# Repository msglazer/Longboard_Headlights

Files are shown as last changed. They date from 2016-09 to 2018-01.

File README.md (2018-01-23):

# Longboard_Headlights
Headlights and Taillights for Longboard project

### Wired Headlight/Tail-light Module:

2X White/Red 1W LED's powered by E-board battery pack
12S(50.4V) Tolerant

### Battery Headlight/Tail-light Module:

2X White/Red 1W LED's powered by an 18650
3+ Hour battery life

#### Common features and Other Info:
Wired version is capable of dimming control through microcontroller, should also be able to make it flash this way as well
Both designs will be mounted through a truck riser. Wired version uses a 1/2" riser.

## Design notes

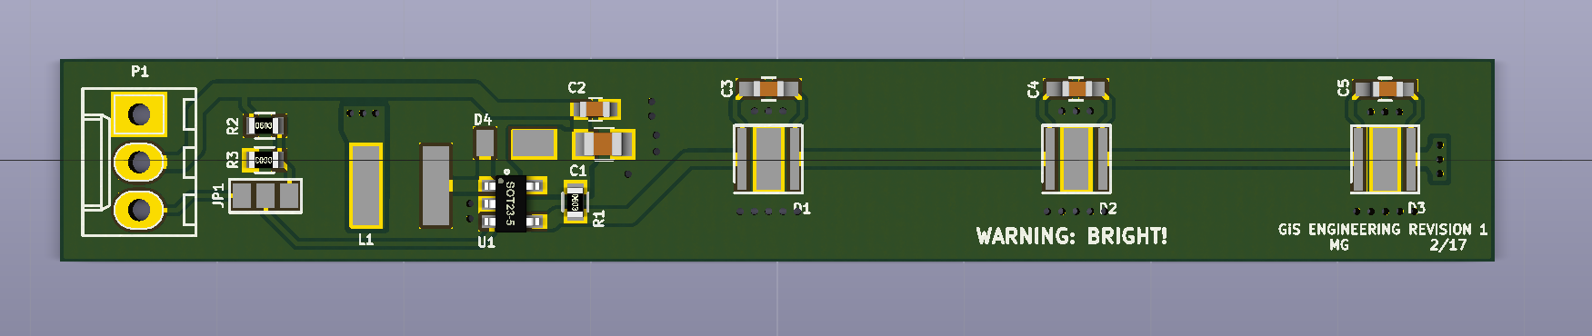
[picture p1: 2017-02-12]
images/PCB_Front.PNG

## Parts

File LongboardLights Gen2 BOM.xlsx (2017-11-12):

Bill of Materials (BOM) - LongboardLights
 |  |  | Green - Forward Lighting, Blue - Rear Lighting, Orange - PCB
Item # | Board Qty | Prod. Qty | Ref Des | Manufacturer | Mfg Part # | Dist. Part # | Price Per Unit | Total Price | Description | Package | Type | Datasheet
1 | 1 | 1 | U1 | Texas Instruments | BQ29700DSER | 296-43985-1-ND | $0.69 | $0.69 | Battery Protection IC | 6-WFDFN | SMD | http://www.ti.com/lit/ds/symlink/bq2971.pdf
3 | 1 | 1 | U2 | Microchip Technology | MCP73833T-FCI/MF | MCP73833T-FCI/MFCT-ND | $0.89 | $0.89 | Battery Charger IC | 10-DFN | SMD | http://www.microchip.com/mymicrochip/filehandler.aspx?ddocname=en027983
4 | 1 | 1 | U3 | Diodes Inc | AP5724FDCG-7 | AP5724FDCGDICT-ND | $0.45 | $0.45 | LED Driver IC | 16-WFQFN | SMD | http://www.ti.com/lit/ds/symlink/tps55330.pdf
5 | 1 | 1 | Q1 | Diodes Inc | DMN2040LTS-13 | DMN2040LTS-13DICT-ND | $0.46 | $0.46 | Dual NMOS common drain | 8-TSSOP | SMD | https://www.diodes.com/assets/Datasheets/ds31941.pdf
6 | 2 | 2 | D2,D3 | Cree Inc | XPGDWT-B1-0000-00LE1 | XPGDWT-B1-0000-00LE1CT-ND | $1.14 | $2.28 | 6500K White LED | 1414 | SMD | http://www.cree.com/led-components/media/documents/dsXPG3.pdf
6 | 2 | 2 | D2,D3 | Cree Inc | XPCRED-L1-R250-00201CT-ND | 941-XPCREDL1R250201 | $1.22 | $2.44 | Red LED | SMD-2 | SMD
7 | 1 | 1 | D1 | Diodes Inc | SS24FL | SS24FLCT-ND | $0.39 | $0.39 | Schottky Diode | SOD-123F | SMD | https://www.fairchildsemi.com/datasheets/SS/SS24FL.pdf
8 | 1 | 1 | C1 | Samsung | CL10B104KO8NNNC | 1276-1005-1-ND | $0.10 | $0.10 | 0.1uF Capacitor | 0603 | SMD
9 | 2 | 2 | C2,C3 | Samsung | CL10A475KO8NNNC | 1276-1784-1-ND | $0.26 | $0.52 | 4.7uF Capacitor | 0603 | SMD
11 | 1 | 1 | C4 | Samsung | CL21A106KOQNNNG | 1276-6455-1-ND | $0.13 | $0.13 | 10uF Capacitor | 0805 | SMD
15 | 1 | 1 | R6 | Samsung | RUT1608FR300CS | 1276-6168-1-ND | $0.17 | $0.17 | 0.3 ohm Resistor | 0603 | SMD
17 | 3 | 1 | R3 | Yageo | RC0603FR-0710KL | 311-10.0KHRCT-ND | $0.10 | $0.10 | 10k ohm resistor | 0603 | SMD
18 | 1 | 1 | R1 | Yageo | RC0603JR-072K2L | 311-2.2KGRCT-ND | $0.10 | $0.10 | 2.2K Ohm Resistor | 0603 | SMD
19 | 1 | 1 | R2 | Yageo | RC0603JR-07330RL | 311-330GRCT-ND | $0.10 | $0.10 | 330 Ohm Resistor | 0603 | SMD
22 | 1 | 1 | R4 | Yageo | RC0603JR-0720KL | 311-20KGRCT-ND | $0.10 | $0.10 | 20K Ohm Resistor | 0603 | SMD
23 | 1 | 1 | R5 | Yageo | RC0603FR-071KL | 311-1.00KHRCT-ND | $0.10 | $0.10 | 1K Ohm Resistor | 0603 | SMD
25 | 1 | 1 | L1 | Taiyo Yuden | NRS4018T220MDGJ | 587-2889-1-ND | $0.29 | $0.29 | 22uH Inductor | 6mm x 6mm | SMD
27 | 1 | 1 | B1 | Keystone Electronics | 1043 | 36-1043-ND | $2.31 | $2.31 | Battery Holder |  | ThruHole
28 | 1 | 1 | SW1 | CW Industries | GPTS203212B | CW182-ND | $0.74 | $0.74 | Power Button |  | ThruHole
29 | 1 | 1 | J1 | Amphenol | 10118194-0001LF | 609-4618-1-ND | $0.46 | $0.46 | Micro USB Port
30 | 1 | 1 | PCB | Oshpark | LR8zDDeL |  | $5.00 | $5.00 | PCB
 |  |  |  |  |  | Board Multiplier: | 1 | Headlight Total:
 |  |  |  |  |  |  |  | $10.38
 |  |  |  |  |  |  |  | Taillight Total:
 |  |  |  |  |  |  |  | $10.54
 |  |  |  |  |  |  |  | PCB Total:
 |  |  |  |  |  |  |  | $5.00
 |  |  |  |  |  |  |  | Grand Total:
 |  |  |  |  |  |  |  | $30.92

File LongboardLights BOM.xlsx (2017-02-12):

Bill of Materials (BOM) - LongboardLights
 |  | Green - Forward Lighting, Blue - Rear Lighting, Orange - PCB
Item # | Qty | Ref Des | Manufacturer | Mfg Part # | Dist. Part # | Price Per Unit | Total Price | Description | Package | Type | Datasheet | Notes
1 | 2 | Q1 | Diodes Inc | AL8805W5-7 | 621-AL8805W5-7 | $0.87 | $1.74 | LED Driver | SOT-25 | SMD | http://www.mouser.com/ds/2/115/AL8805-59388.pdf
2 | 6 | D1,D2,D3 | Cree Inc | XPGDWT-B1-0000-00LE3 | 941-XPGDWTB100LE3 | $1.79 | $10.74 | White LED | SMD-2 | SMD | http://www.mouser.com/ds/2/90/dsXPG3-931454.pdf
3 | 2 | C1 | Murata Electronics | GRM21BR61E475KA12L | 81-GRM21BR61E475KA12 | $0.15 | $0.30 | 4.7uF Capacitor | 0805 | SMD
4 | 2 | C2 | Murata Electronics | GRM188R61E225MA12D | 81-GRM188R61E225MA2D | $0.12 | $0.24 | 2.2uF Capacitor | 0603 | SMD
5 | 6 | C3,C4,C5 |  | GRM188R61E105KA12D | 81-GRM188R61E105KA12 | $0.10 | $0.60 | 1uF Capacitor | 0603 | SMD
6 | 2 | R1 | TE Connectivity | RLP73N2AR30JTD | 279-RLP73N2AR30JTD | $0.10 | $0.20 | 0.3 ohm resistor | 0603 | SMD
7 | 2 | R2 | Yageo | RC0603FR-0738K3L | 603-RC0603FR-0738K3L | $0.09 | $0.18 | 38k ohm resistor | 0603 | SMD |  | order 10
8 | 2 | R3 | Panasonic | ERJ-3GEYJ103V | 667-ERJ-3GEYJ103V | $0.08 | $0.16 | 10k ohm resistor | 0603 | SMD
9 | 2 | L1 | Laird Technologies | TYS5040101M-10 | 875-TYS5040101M-10 | $0.51 | $1.02 | 100uH Inductor | 5mm x 5mm | SMD | http://www.mouser.com/ds/2/223/SIP-DS-TYS%205040%200413-537395.pdf
10 | 2 | D4 | Diodes Inc | DFLS1200-7 | 621-DFLS1200-F | $0.58 | $1.16 | Schottky Diode | PowerDI-123 | SMD
12 | 6 | D1,D2 | Cree Inc | XPCRED-L1-R250-00201 | 941-XPCREDL1R250201 | $1.58 | $9.48 | Red LED | SMD-2 | SMD
23 | 1 | PCB | Oshpark | LR8zDDeL |  | $2.15 | $2.15
 |  |  |  |  | Board Multiplier: | 2 | Headlight Total:
 |  |  |  |  |  |  | $16.34
 |  |  |  |  |  |  | Taillight Total:
 |  |  |  |  |  |  | $15.08
 |  |  |  |  |  |  | PCB Total:
 |  |  |  |  |  |  | $2.15
 |  |  |  |  |  |  | Grand Total:
 |  |  |  |  |  |  | $35.72

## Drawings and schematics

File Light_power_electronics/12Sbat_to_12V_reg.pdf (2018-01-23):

## WEBENCH ® Design Report

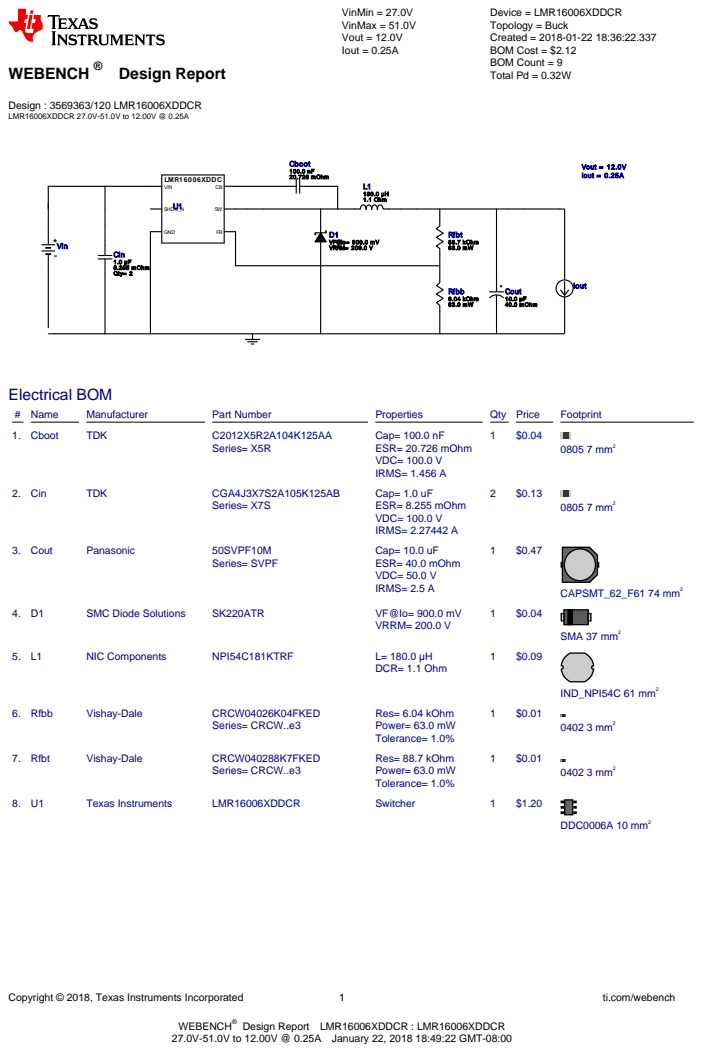
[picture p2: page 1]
Copyright © 2018, Texas Instruments Incorporated; ti.com/webench; Design Report LMR16006XDDCR : LMR16006XDDCR; Design : 3569363/120 LMR16006XDDCR LMR16006XDDCR 27.0V-51.0V to 12.00V @ 0.25A; VinMin = 27.0V VinMax = 51.0V Vout = 12.0V Iout = 0.25A; Device = LMR16006XDDCR Topology = Buck Created = 2018-01-22 18:36:22.337 BOM Cost = $2.12 BOM Count = 9 Total Pd = 0.32W; Cboot 100.0 nF 20.726 mOhm; Cin 1.0 µF 8.255 mOhm Qty= 2; Cout 10.0 µF 40.0 mOhm; D1 VF@Io= 900.0 mV VRRM= 200.0 V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

WEBENCH®
27.0V-51.0V to 12.00V @ 0.25A January 22, 2018 18:49:22 GMT-08:00

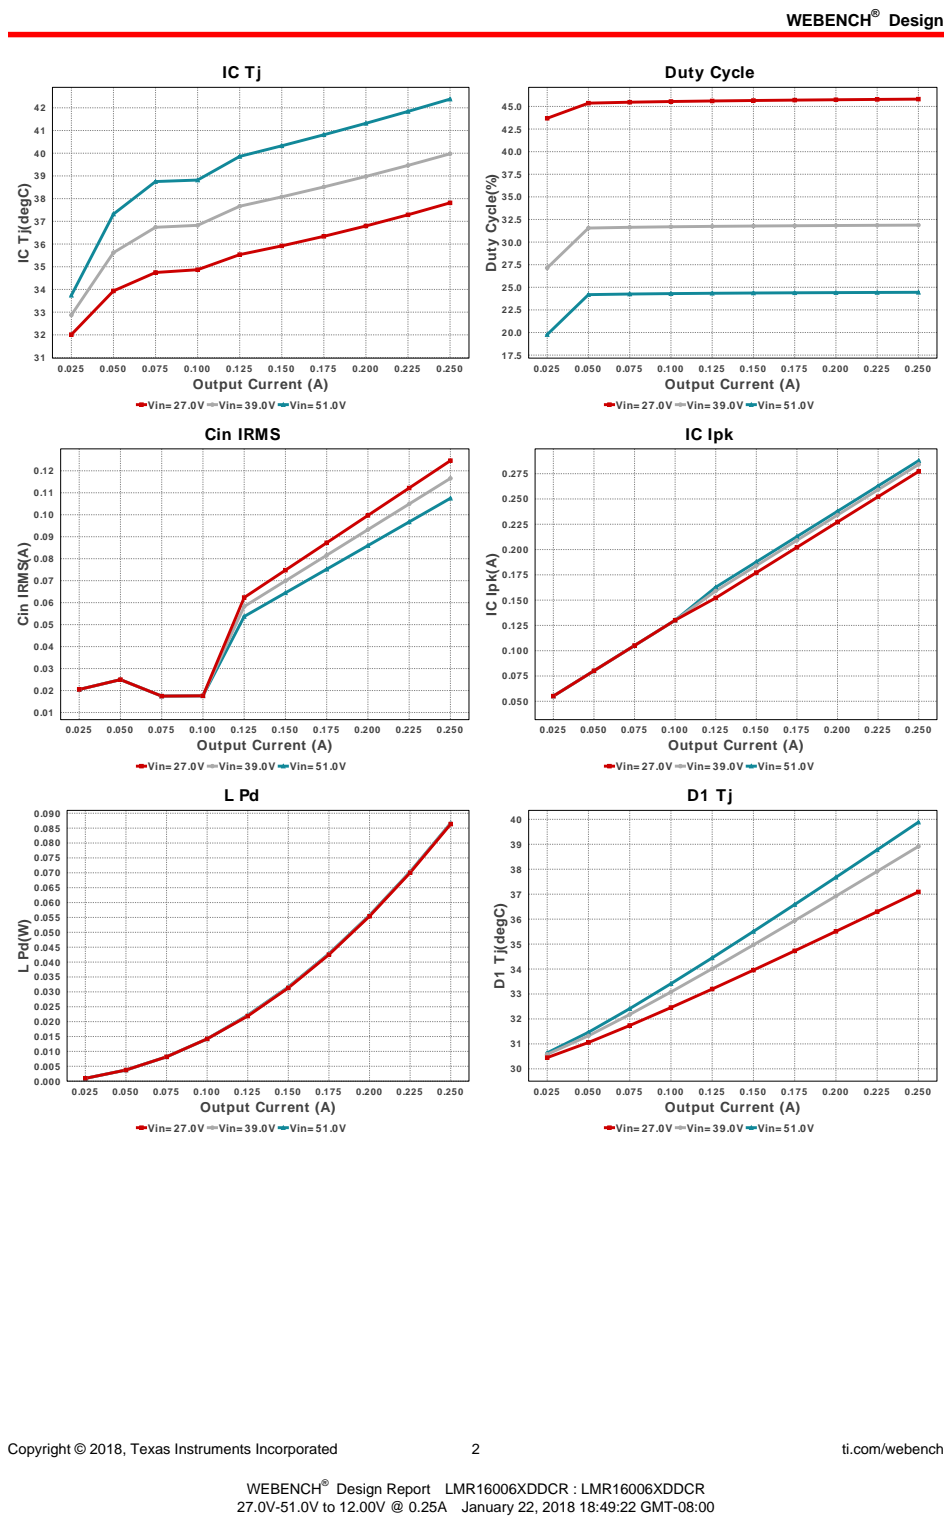
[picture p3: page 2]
Design; Copyright © 2018, Texas Instruments Incorporated; ti.com/webench; 0.250 Output Current (A); Duty Cycle; Duty Cycle(%); Cin IRMS(A); IC Ipk; IC Ipk(A); D1 Tj(degC)

IC Tj(degC)

Vin= 27.0V Vin= 39.0V Vin= 51.0V
Cin IRMS

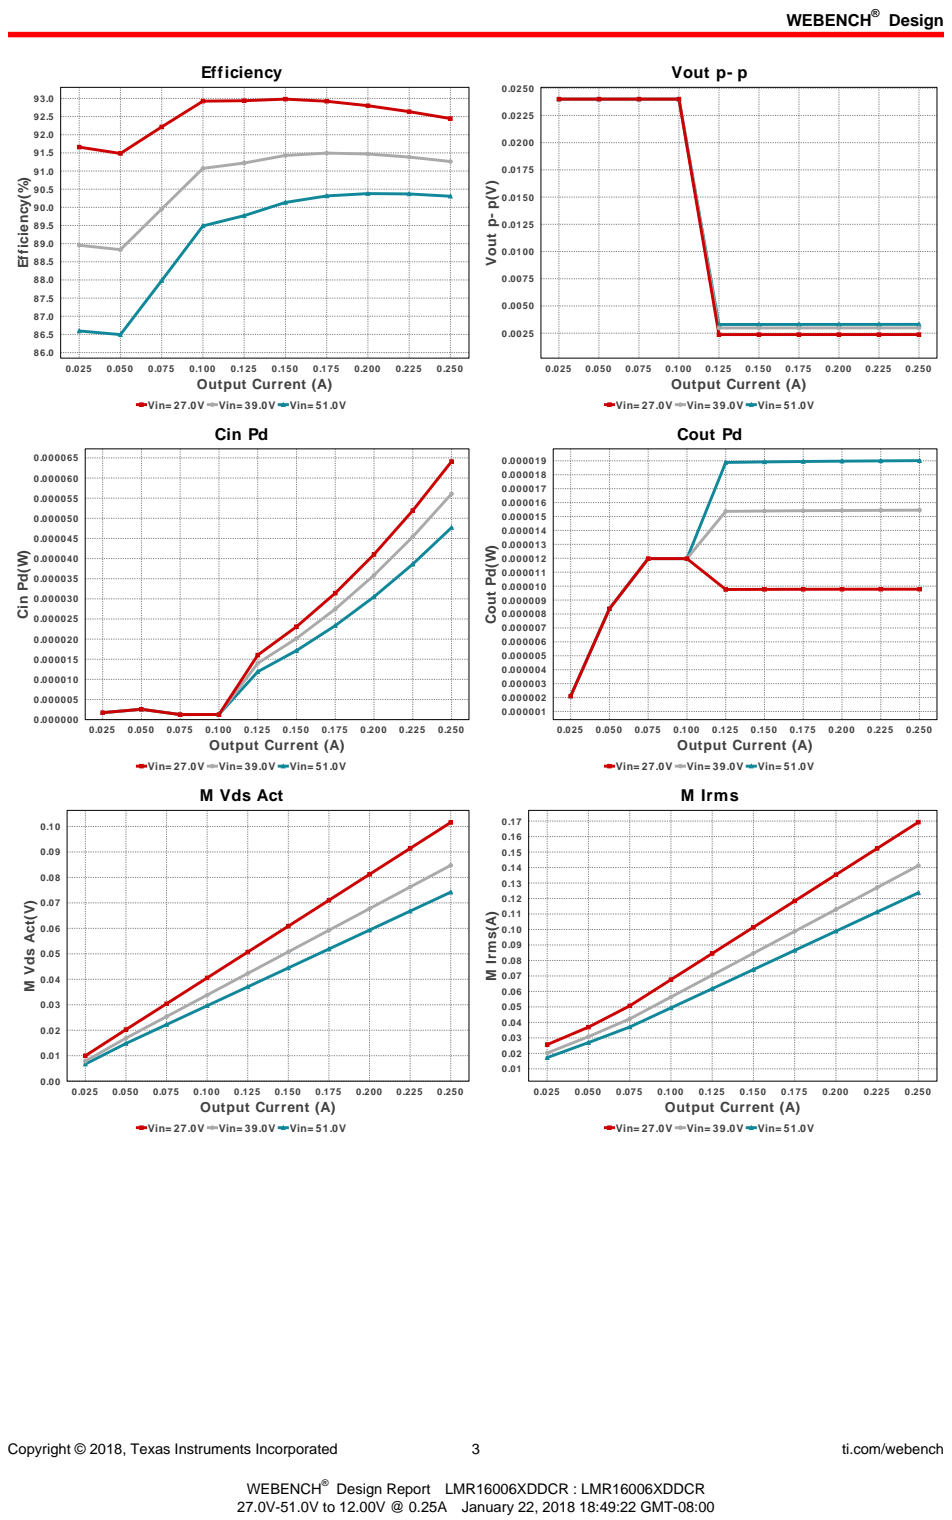
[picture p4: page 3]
Copyright © 2018, Texas Instruments Incorporated; ti.com/webench; Efficiency; 0.250 Output Current (A); Efficiency(%); Vout p- p; Vout p- p(V); Cin Pd; 0.025 0.050 0.075 0.100 0.125 0.150 0.175 0.200 0.225 0.250 Output Current (A); Cin Pd(W); Cout Pd; Cout Pd(W); M Vds Act(V); M Irms; M Irms(A)

Vin= 27.0V Vin= 39.0V Vin= 51.0V

M Vds Act

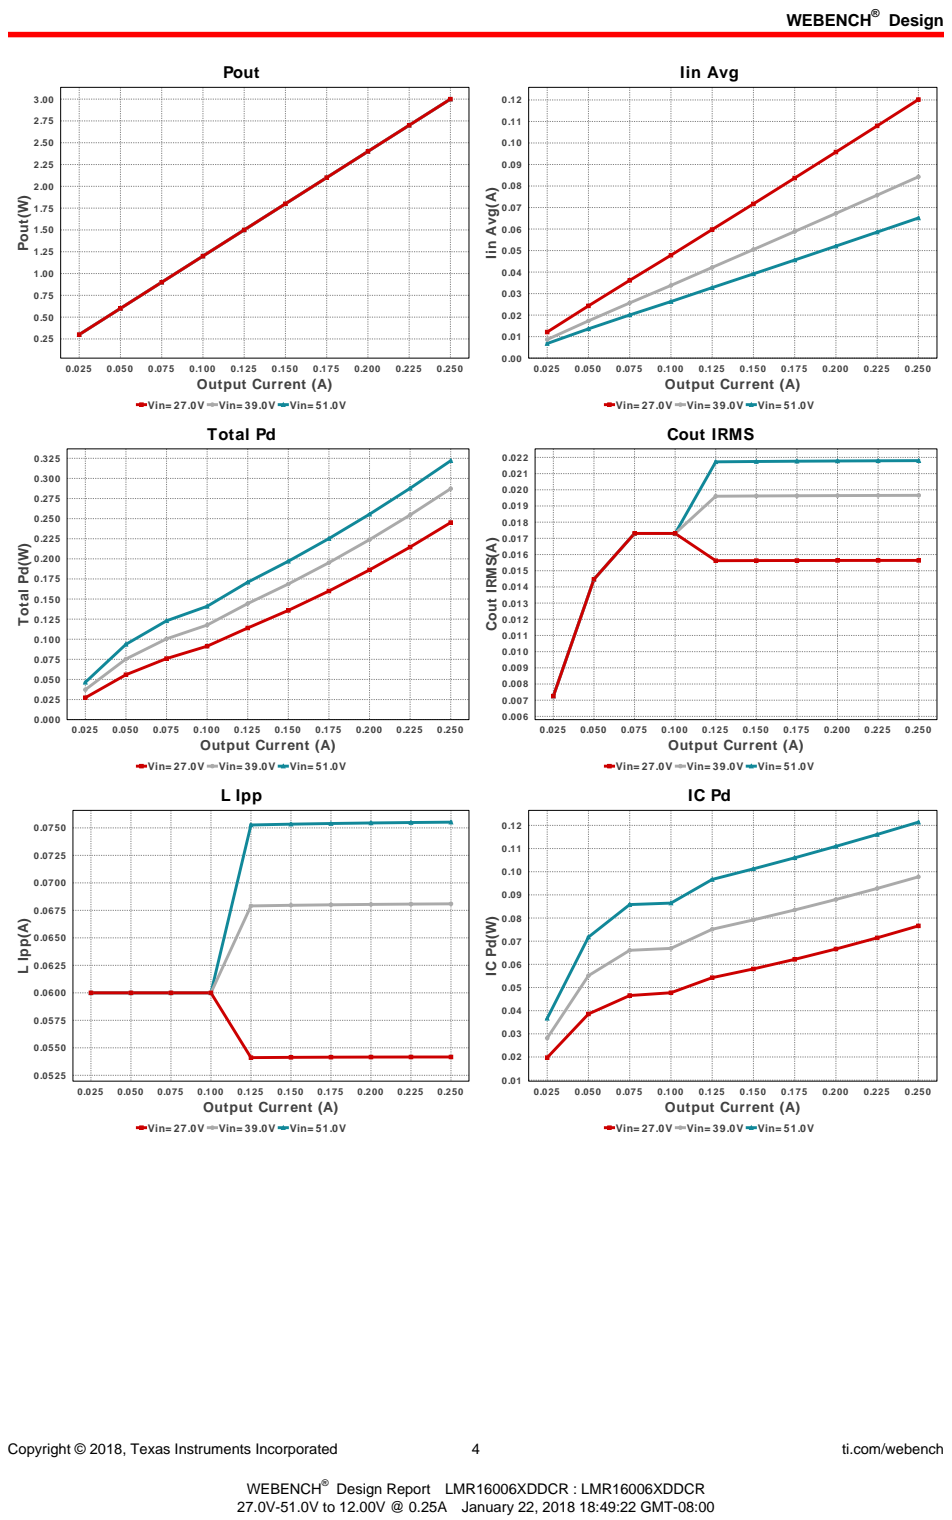
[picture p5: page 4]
Copyright © 2018, Texas Instruments Incorporated; ti.com/webench; Pout; 0.250 Output Current (A); Pout(W); Iin Avg; Iin Avg(A); Total Pd; Total Pd(W); Cout IRMS(A); L Ipp; L Ipp(A)

Vin= 27.0V Vin= 39.0V Vin= 51.0V

Cout IRMS

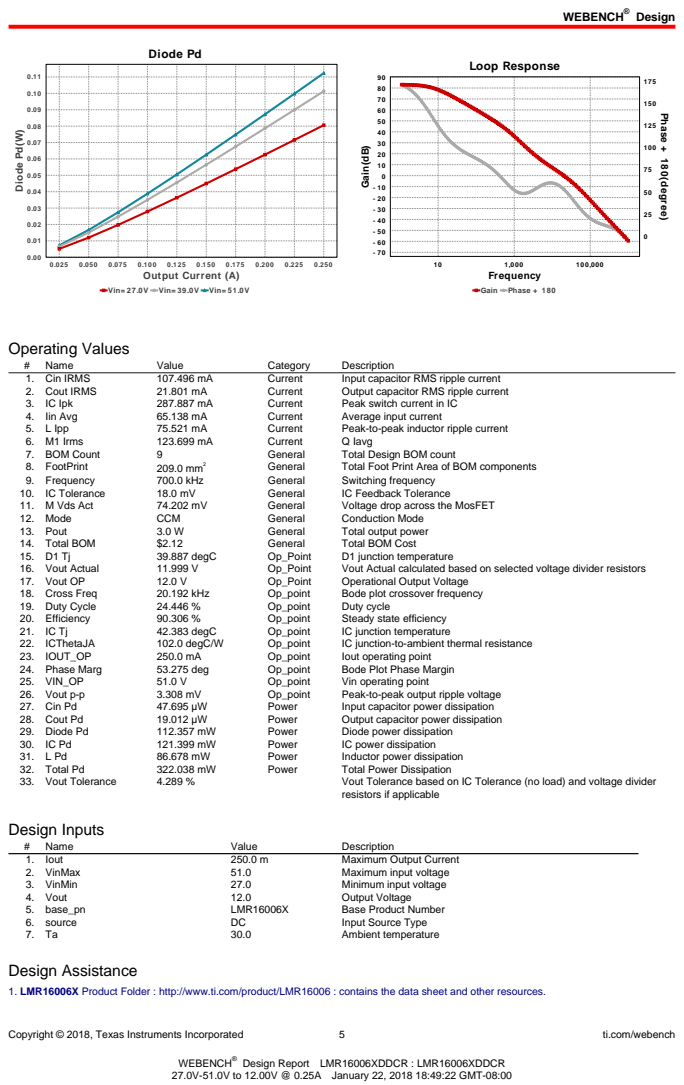
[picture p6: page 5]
Copyright © 2018, Texas Instruments Incorporated; ti.com/webench; Diode Pd; 0.250 Output Current (A); Diode Pd(W); Loop Response; Gain Phase + 180; 100,000 Frequency; Gain(dB); Phase + 180(degree); Operating Values; Name; Value; Category; Description; 1. Cin IRMS; Current; Input capacitor RMS ripple current; 2. Cout IRMS; Output capacitor RMS ripple current; 3. IC Ipk; Peak switch current in IC; 4. Iin Avg; Average input current; 5. L Ipp; Peak-to-peak inductor ripple current; 6. M1 Irms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

Vin= 27.0V Vin= 39.0V Vin= 51.0V

resistors if applicable

1. LMR16006X Product Folder : http://www.ti.com/product/LMR16006 : contains the data sheet and other resources.

Copyright © 2018, Texas Instruments Incorporated | 6 | ti.com/webench

Texas Instruments' WEBENCH simulation tools attempt to recreate the performance of a substantially equivalent physical implementation
of the design. Simulations are created using Texas Instruments' published specifications as well as the published specifications of other device manufacturers. While Texas Instruments does update this information periodically, this information may not be current at the time the simulation is built. Texas Instruments does not warrant the accuracy or completeness of the specifications or any information contained therein. Texas Instruments does not warrant that any designs or recommended parts will meet the specifications you entered, will be suitable for your application or fit for any particular purpose, or will operate as shown in the simulation in a physical implementation. Texas Instruments does not warrant that the designs are production worthy.
You should completely validate and test your design implementation to confirm the system functionality for your application prior to production.
Use of Texas Instruments' WEBENCH simulation tools is subject to Texas Instruments' Site Terms and Conditions of Use. (http://www.ti.com/corp/docs/legal/termsofuse.shtml) Prototype boards based on WEBENCH created designs are provided AS IS without warranty of any kind for evaluation and testing purposes and are subject to the terms of the Evaluation License Agreement. (http://www.ti.com/corp/docs/legal/termsofuse_estore.shtml)

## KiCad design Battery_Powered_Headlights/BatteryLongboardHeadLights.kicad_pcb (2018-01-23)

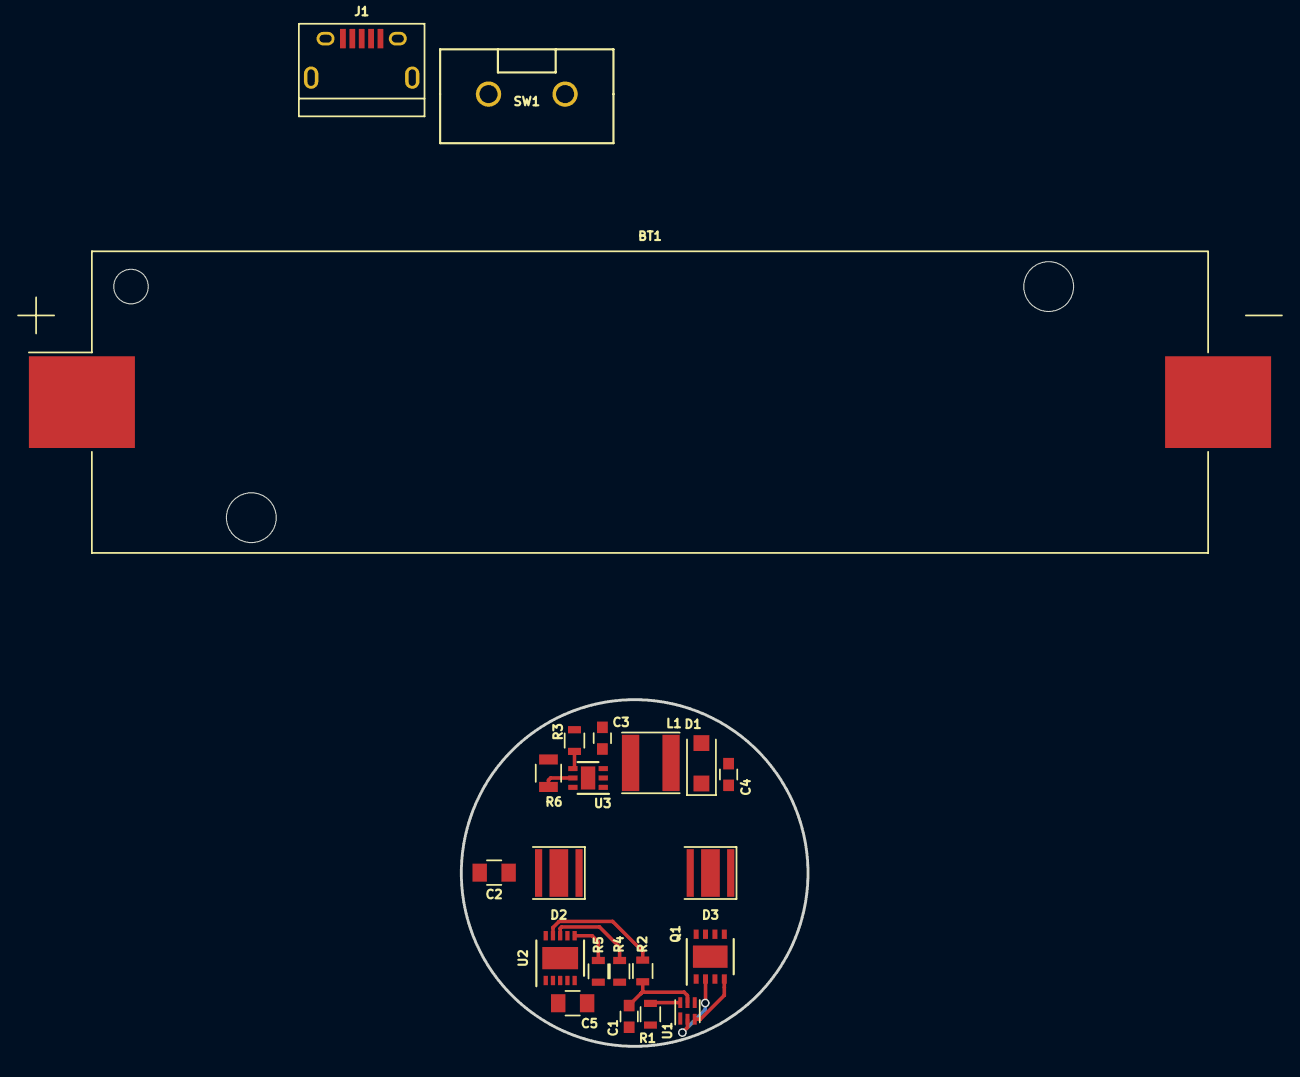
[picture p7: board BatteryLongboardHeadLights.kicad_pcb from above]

Board: 2 copper layers, 24.0 x 24.0 mm, 22 parts (0 on the bottom side), 15 nets.

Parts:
BT1: Battery_Cell; Keystone_1042_1x18650
C1: 0.1uF; C_0603
C2, C5: 4.7uF; C_0805
C3: 4.7uF; C_0603
C4: 10uF; C_0603
D1: D_Schottky; D_SOD-123F
D2, D3: LED; LED_Cree-XP-G
J1: USB_OTG; USB_Micro-B
L1: 22uH; L_Taiyo-Yuden_NR-40xx
Q1: DMN2028UFDH-7; DFN-8-1EP_3x3mm_Pitch0.65mm
R1: 2.2K; R_0603
R2: 330; R_0603
R3: 10K; R_0603
R4: 20K; R_0603
R5: 1K; R_0603
R6: 0.3; R_0805
SW1: SW_Push; GPTS203212B
U1: bq29700; WSON6_1.5x1.5mm_Pitch0.5mm
U2: MCP73833T; DFN-10-1EP_3x3mm_Pitch0.5mm
U3: AP5724; DFN-6-1EP_2x2mm_Pitch0.65mm

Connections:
+BATT: BT1.1, C2.1, C3.1, L1.1, R2.1, SW1.1, U2.9, U2.10, U3.2
/SWITCH: R3.1, SW1.2, U3.4
/USB_IN: C5.1, J1.1, U2.1, U2.2
/VBAT_NEG: BT1.2, C1.2, Q1.3, R1.2, U1.4
GND: C2.2, C3.2, C4.2, C5.2, J1.5, J1.6, Q1.1, R3.2, R4.2, R5.2, R6.2, U2.5, U3.6
unnamed: C1.1, R2.2, U1.5
unnamed: C4.1, D1.1, D2.2, U3.3
unnamed: D1.2, L1.2, U3.1
unnamed: D2.1, D3.2
unnamed: D3.1, R6.1, U3.5
unnamed: Q1.2, U1.2
unnamed: Q1.4, U1.3
unnamed: R1.1, U1.6
unnamed: R4.1, U2.8
unnamed: R5.1, U2.6

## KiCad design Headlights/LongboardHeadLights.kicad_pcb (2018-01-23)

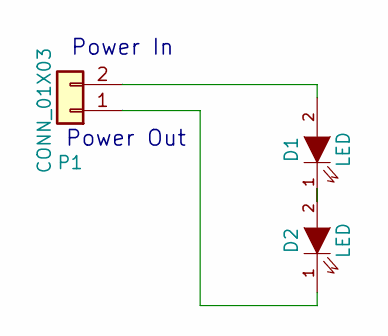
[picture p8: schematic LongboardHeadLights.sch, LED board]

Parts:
D1, D2: LED; LED-XP-G_CREE
P1: CONN_01X03; JST_EH_B02B-EH-A_02x2.50mm_Straight

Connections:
GND: D1.3, D2.3
unnamed: D1.1 (K), D2.2 (A)
unnamed: D1.2 (A), P1.2
unnamed: D2.1 (K), P1.1

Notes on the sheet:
Power In
Power Out

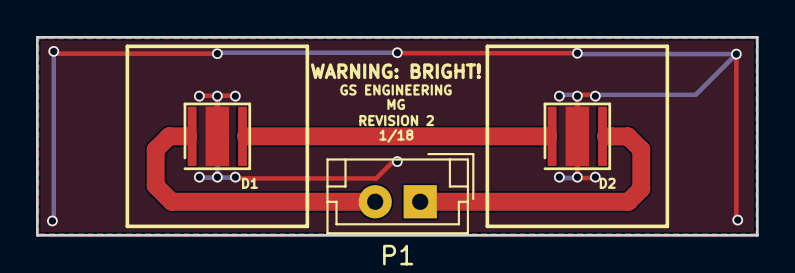
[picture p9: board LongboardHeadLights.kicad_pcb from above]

Board: 2 copper layers, 40.0 x 11.0 mm, 3 parts (0 on the bottom side), 4 nets.

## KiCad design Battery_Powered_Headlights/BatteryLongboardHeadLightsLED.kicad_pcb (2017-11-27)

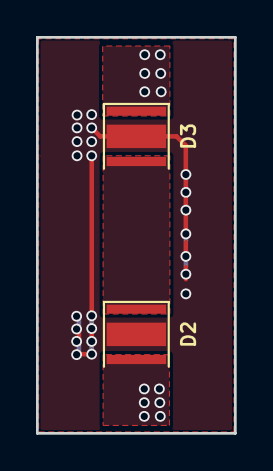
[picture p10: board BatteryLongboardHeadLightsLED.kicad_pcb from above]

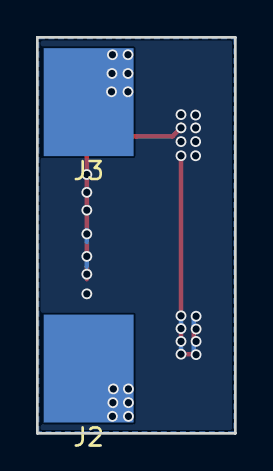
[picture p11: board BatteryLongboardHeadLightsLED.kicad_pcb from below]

Board: 2 copper layers, 11.0 x 22.0 mm, 4 parts (2 on the bottom side), 4 nets.

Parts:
D2, D3: LED; LED_Cree-XP-G
J2, J3: Conn_01x01; SolderWirePad_single_SMD_5x6mm

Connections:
GND: D2.3, D3.3
unnamed: D2.2, J2.1
unnamed: D2.1, D3.2
unnamed: D3.1, J3.1

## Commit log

2016-10-01 initial schematic build out
2016-10-14 PCB work
2016-10-14 small schematic changes
    [LongboardHeadLights.sch, LongboardTailLights.sch]
2016-10-14 updated BOM
    [LongboardLights BOM.xlsx]
2016-11-16 Generated Gerbers
    [LongboardHeadLights-B.Adhes.gbr, LongboardHeadLights-B.Cu.gbr, LongboardHeadLights-B.Mask.gbr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]
2016-11-16 updated project and completed rev 1 PCB
    [LongboardHeadLights.kicad_pcb]
2017-02-11 finished PCB, updating plan
    ditched tail light turn signal idea, now only need one PCB and just
    switch out LEDs
    [LongboardHeadLights.kicad_pcb, LongboardHeadLights.sch, LongboardLights BOM.xlsx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]
2017-02-11 couple quick changes
    [LongboardHeadLights.kicad_pcb, LongboardHeadLights.sch]
2017-02-11 fixed a bad trace
    [LongboardHeadLights.kicad_pcb]
2017-02-11 yet another fix
    [LongboardHeadLights.kicad_pcb]
2017-02-12 another small tweak
    [LongboardHeadLights.kicad_pcb]
2017-02-12 added a PCB image
2017-02-12 fixed BOM
    [LongboardLights BOM.xlsx]
2017-10-31 redesigning the headlights to be battery powered
    [BatteryLongboardHeadLights.kicad_pcb, BatteryLongboardHeadLights.sch, LongboardLights Gen2 BOM.xlsx]
2017-11-01 schematic changes nearly done
    [BatteryLongboardHeadLights.sch]
2017-11-01 updating BOM
    [LongboardLights Gen2 BOM.xlsx]
2017-11-02 Schematic done, values almost, layout next
    [BatteryLongboardHeadLights.sch]
2017-11-02 BOM update
    [LongboardLights Gen2 BOM.xlsx]
2017-11-06 schematic completed
    [BatteryLongboardHeadLights.sch]
2017-11-06 BOM completed
    [LongboardLights Gen2 BOM.xlsx]
2017-11-12 PCB work in progress
    [BatteryLongboardHeadLights.kicad_pcb]
2017-11-19 PCB layout for the Batteryboard/LEDcontroller done
    [BatteryLongboardHeadLights.kicad_pcb, BatteryLongboardHeadLightsLED.kicad_pcb, _saved_BatteryLongboardHeadLights.sch]
2017-11-27 PCB's should now be orderable
    [BatteryLongboardHeadLights.kicad_pcb, BatteryLongboardHeadLightsLED.kicad_pcb]
2018-01-23 updating designs for newest revision; removing unneeded files
    [BatteryLongboardHeadLights.kicad_pcb, BatteryLongboardHeadLights.sch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]
2018-01-23 bulk of power electronics schematic done
    [power_electronics.sch]
2018-01-24 schematic done, adding footprints
    [power_electronics.sch]
